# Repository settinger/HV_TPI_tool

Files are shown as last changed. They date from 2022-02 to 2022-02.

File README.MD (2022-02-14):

# High-Voltage Tiny Programming Interface (HVTPI) Tool

For an upcoming project I needed a way to use the High-Voltage Tiny Programming Interface (HVTPI) protocol. If you're at all familiar with the High-Voltage Serial Programming (HVSP) that can be used on most ATmegas and ATtinys that use the SPI protocol, then you would be justified to assume HVTPI is a convoluted process dissimilar from standard TPI. But, mercifully, that is not the case! HVTPI is just TPI, but instead of pulling the <span style="text-decoration:overline">RESET</span> pin LOW, you pull it up to 12V.

Two low-cost options for TPI programming are the [USBasp](https://www.fischl.de/usbasp/) (with the [latest firmware](https://blog.podkalicki.com/how-to-update-avr-usbasp-firmware-to-latest-version/)) or the [TPI Programming Arduino Sketch](http://junkplusarduino.blogspot.com/p/attiny10-resources.html) by Junk+Arduino and others. Neither the USBasp nor the Arduino has a pin available to output 12V, of course. That requires some extra hardware.

The task is easy to summarize. Create a new signal that produces 5V when <span style="text-decoration:overline">RESET</span> produces 5V, and goes to 12V when <span style="text-decoration:overline">RESET</span> goes to 0V. On YouTube, [fVripple made a very good one with an optoisolator and a benchtop power supply](https://www.youtube.com/watch?v=7YJOtHbnNDQ), but I wanted to stick to parts I had on-hand and make it more portable. This is what I came up with:

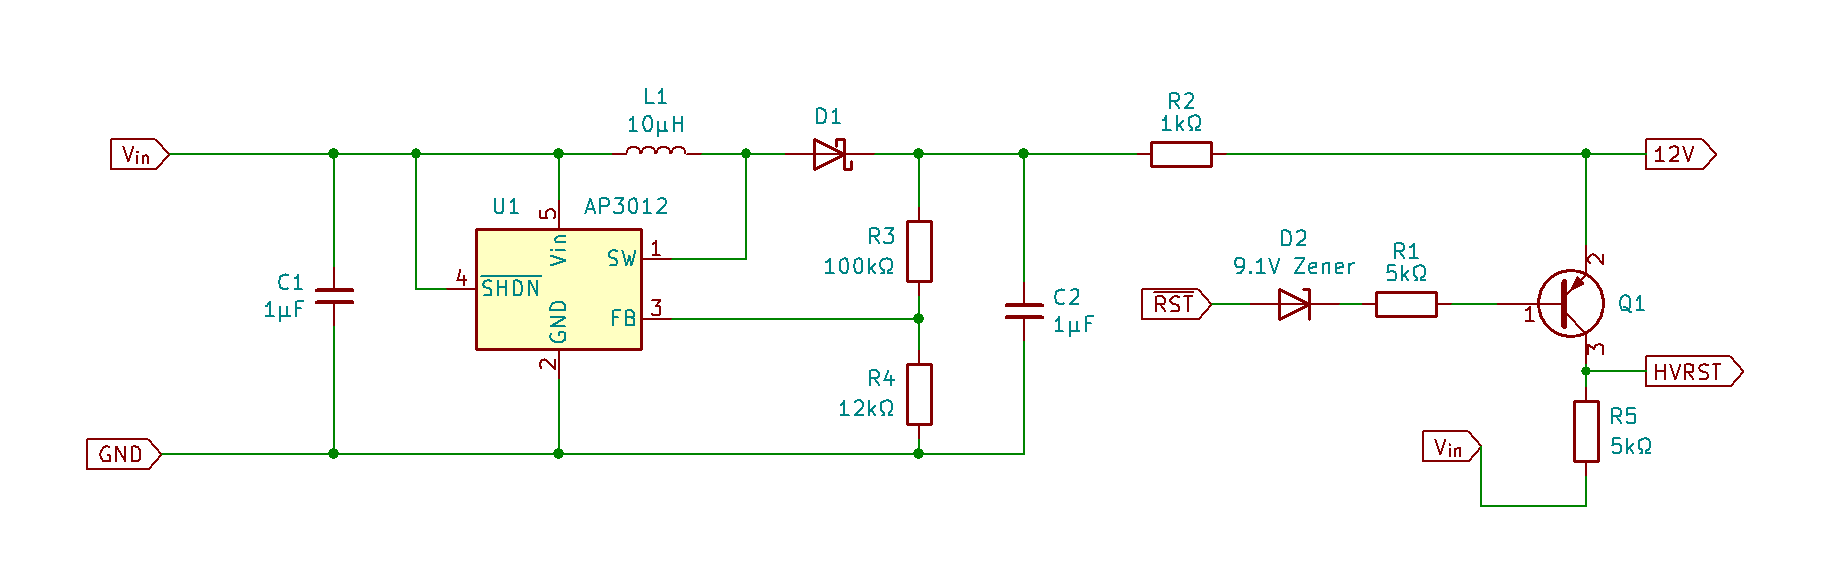
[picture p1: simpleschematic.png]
A schematic showing a 12V boost converter and an output that switches between 12V and 5V


An AP3012 boost converter gives us 12V all the time. While <span style="text-decoration:overline">RESET</span> is HIGH, the forward voltage of the Zener diode is high enough that no current flows through the PNP BJT and the output is equal to <span style="text-decoration:overline">RESET</span>. When <span style="text-decoration:overline">RESET</span> goes LOW, current flows through the 9.1V Zener diode, driving the output to 12V. The 5kΩ resistor value is not a precise one; I think I used 3.3kΩ in practice. And I broke out the 12V signal in case I ever wanted to use it for something else, I dunno what though.

To actually use this schematic, I made two designs: one to go with the USBasp and one to go with the Arduino TPI programmer. I was very sleep-deprived and made some silly design choices.

## The USBasp HVTPI tool

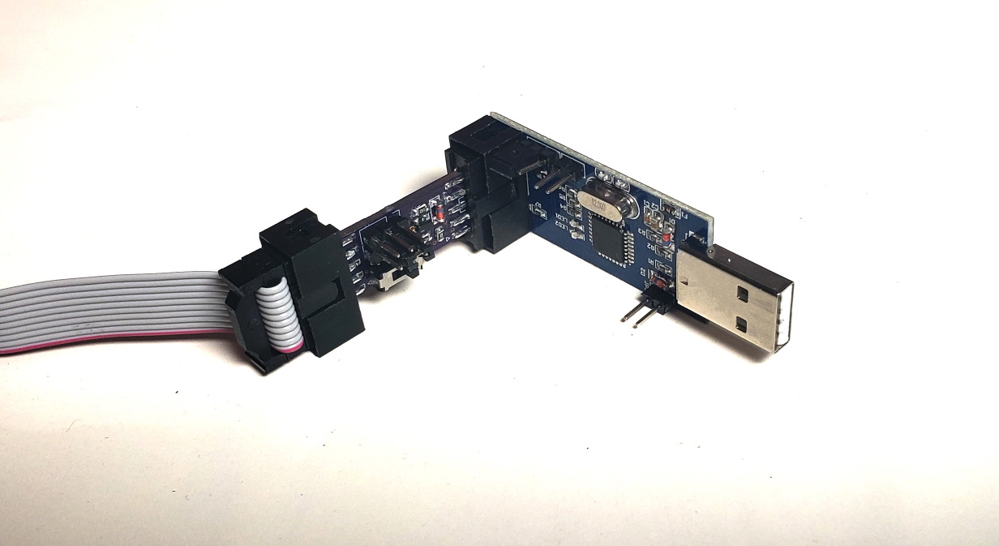
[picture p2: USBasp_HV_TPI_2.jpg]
A photo of the HVTPI PCB inserted into the end of a USBasp programmer


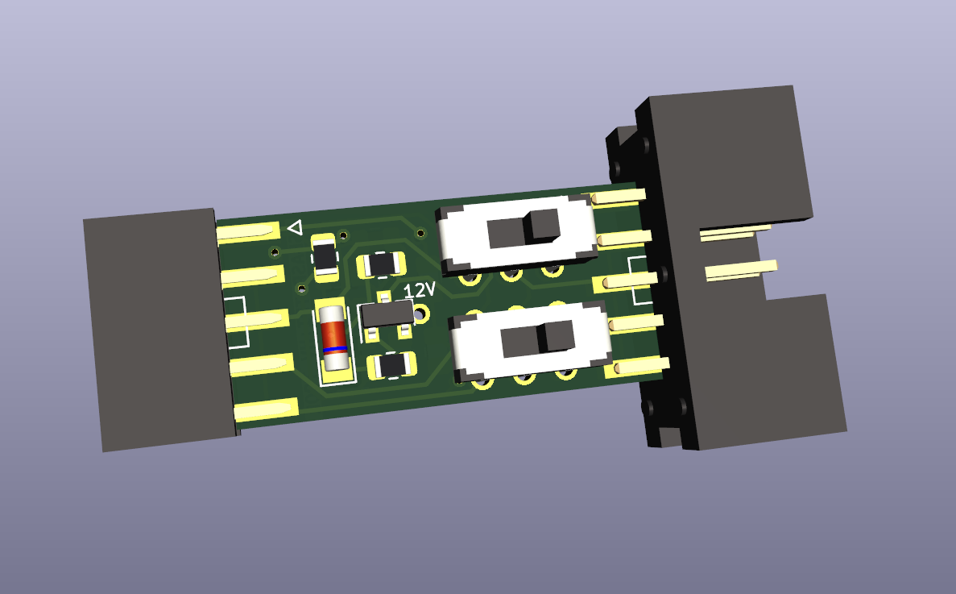
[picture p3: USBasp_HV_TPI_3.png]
A KiCad render of the HVTPI PCB


The USBasp HVTPI tool mates nicely with its 2×5 IDC headers. There are two SPDT switches, one to switch between normal TPI and HVTPI modes, and another to combine the two data lines as described in [this application note](http://ww1.microchip.com/downloads/en/AppNotes/doc8373.pdf):

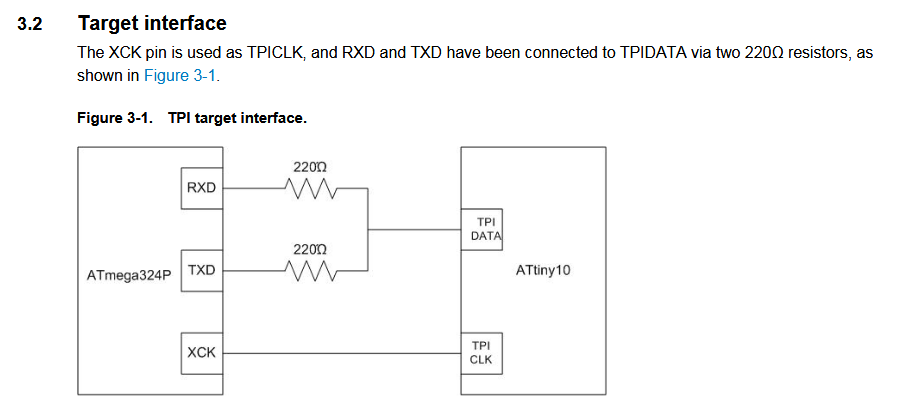
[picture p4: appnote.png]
A diagram from a Microchip application note showing how it recommends connecting an ATtiny10 to a programmer with a 220Ω resistor on each data line


These resistors are not always necessary, which is why they can be disconnected with the switch. The USBasp expects a circuit with a programming pinout like this:

A 2-by-3 pinout diagram showing (from top-left counterclockwise) (NC), TPICLK, ~RESET, GND, TPIDATA, VCC

Consequently, the line that is normally labelled "MOSI" acts as the bidirectional line when the USBasp does TPI stuff. This becomes a problem if you are using a circuit that was designed for the [Atmel-ICE](https://ww1.microchip.com/downloads/en/DeviceDoc/Atmel-ICE_UserGuide.pdf), which expects a programming pinout like this:

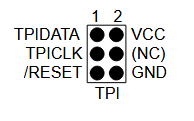
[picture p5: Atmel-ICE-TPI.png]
A 2-by-3 pinout diagram showing (from top-left counterclockwise) TPIDATA, TPICLK, ~RESET, GND, (NC), VCC


Both configurations are handled equally well by the 220Ω-resistor switch.

Using the HVTPI tool is as easy as normal TPI. As far as your computer is concerned, there is no difference between this and a normal TPI setup, so no instructions or makefiles have to change.

## The Arduino HVTPI tool

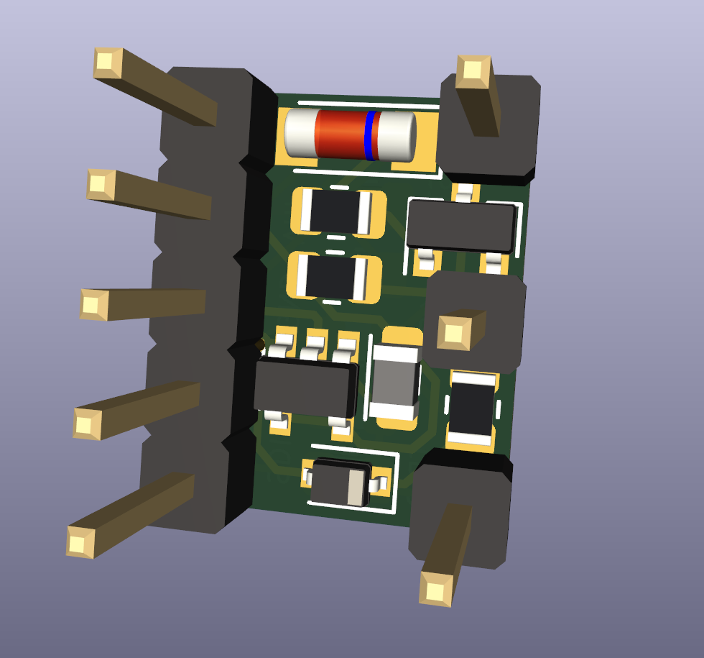
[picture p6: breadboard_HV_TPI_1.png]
A KiCad render of a surface-mount PCB the size of a 10-DIP chip


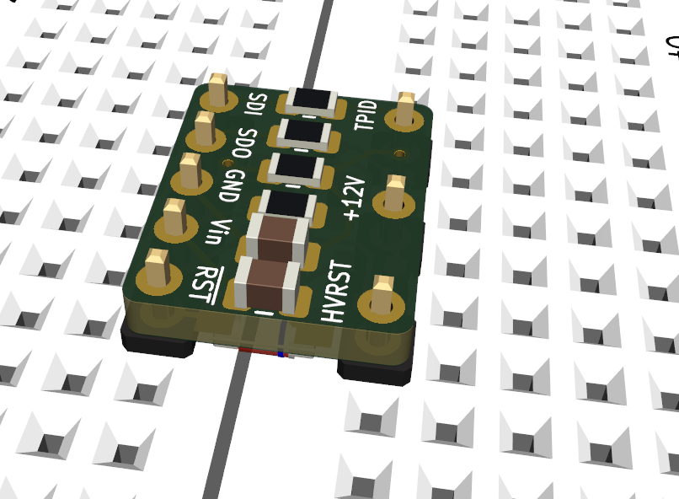
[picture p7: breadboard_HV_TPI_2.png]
A KiCad render of the same PCB placed on a breadboard


The Arduino-compatible programmer is designed to sit in a breadboard. I originally designed it very skinny, with the HVRST line sticking up like so:

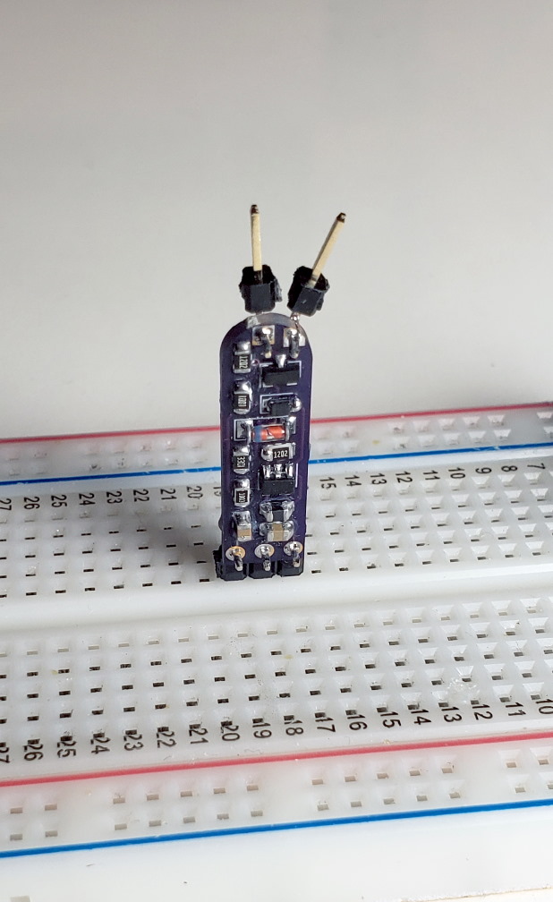
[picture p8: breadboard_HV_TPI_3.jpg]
A photo of the earlier design, which is skinny and tall and has two pins at weird angles sticking out of the top


This is not very helpful, so later I went back and put it in a more reasonable 10-DIP layout. Because the Arduino program expects both MISO and MOSI lines to connect to the TPI DATA line via 220Ω resistors, I built that into this board as well. Again, there is no need to make any changes to the normal TPI programming workflow. I know the Arduino sketch has some "HVP" options available, but with this board they are wholly unnecessary.

I'm happily using these with both the USBasp and the Arduino for HVTPI programming. I had a hard time finding good resources for HVTPI and had to do a lot of learning-by-doing, but hopefully I can pass that knowledge along and save someone some trouble.

# Note to self

After setting the ATtiny4/5/9/10/20/40 fuse bits to `0xFE` (or whatever) to enable 12V reset, avrdude can't just overwrite the fuses with `0xFF`. Using the flags `-x section_config -e` will clear the bits.

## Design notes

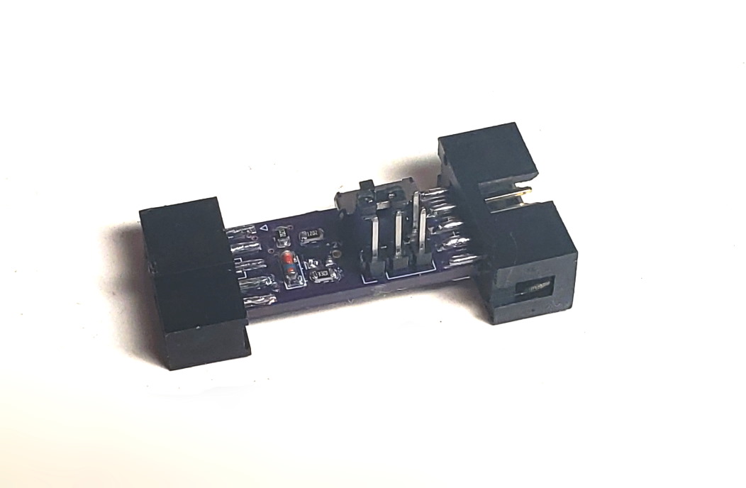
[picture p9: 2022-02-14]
USBasp_HV_TPI_1.jpg

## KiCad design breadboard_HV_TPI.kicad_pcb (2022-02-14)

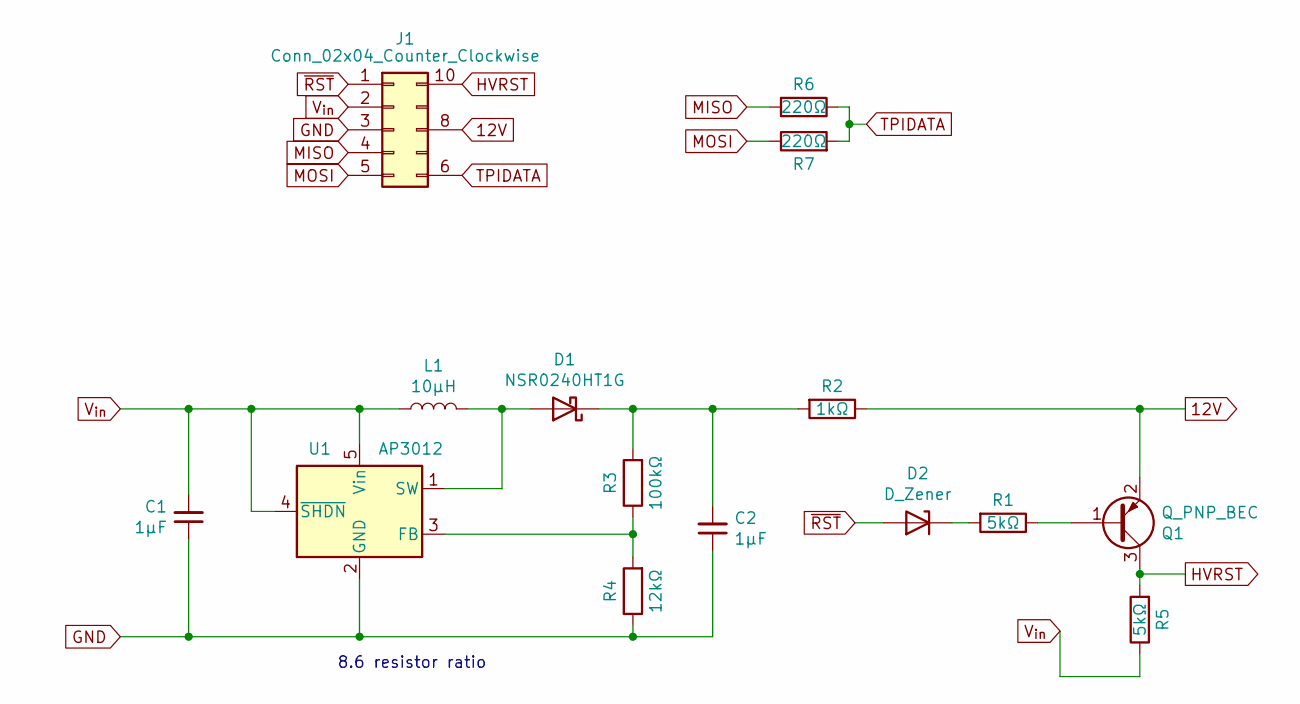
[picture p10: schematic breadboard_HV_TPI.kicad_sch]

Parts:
C1, C2: 1μF; C_0805_2012Metric
D1: NSR0240HT1G; D_SOD-323
D2: D_Zener; D_MiniMELF
J1: Conn_02x04_Counter_Clockwise; DIP-10_W7.62mm
L1: 10μH; L_0805_2012Metric
Q1: Q_PNP_BEC; SOT-23
R1, R5: 5kΩ; R_0805_2012Metric
R2: 1kΩ; R_0805_2012Metric
R3: 100kΩ; R_0805_2012Metric
R4: 12kΩ; R_0805_2012Metric
R6, R7: 220Ω; R_0805_2012Metric
U1: AP3012; SOT-23-5

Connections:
12V: J1.8, Q1.2 (E), R2.1
GND: C1.1, C2.1, J1.3, R4.1, U1.2 (GND)
HVRST: J1.10, Q1.3 (C), R5.2
MISO: J1.4, R6.2
MOSI: J1.5, R7.1
unnamed: C2.2, D1.1 (K), R2.2, R3.2
unnamed: D1.2 (A), L1.2, U1.1 (SW)
unnamed: D2.1 (K), R1.2
unnamed: Q1.1 (B), R1.1
unnamed: R3.1, R4.2, U1.3 (FB)
TPIDATA: J1.6, R6.1, R7.2
V_{in}: C1.2, J1.2, L1.1, R5.1, U1.4 (~SHDN), U1.5 (Vin)
~RST: D2.2 (A), J1.1

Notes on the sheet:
8.6 resistor ratio

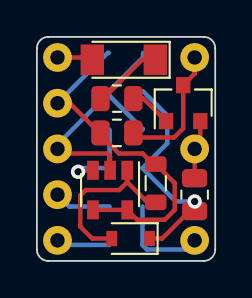
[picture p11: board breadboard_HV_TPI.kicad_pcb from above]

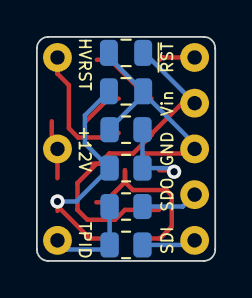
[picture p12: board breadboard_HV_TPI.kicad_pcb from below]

Board: 2 copper layers, 9.9 x 12.4 mm, 15 parts (6 on the bottom side), 13 nets.

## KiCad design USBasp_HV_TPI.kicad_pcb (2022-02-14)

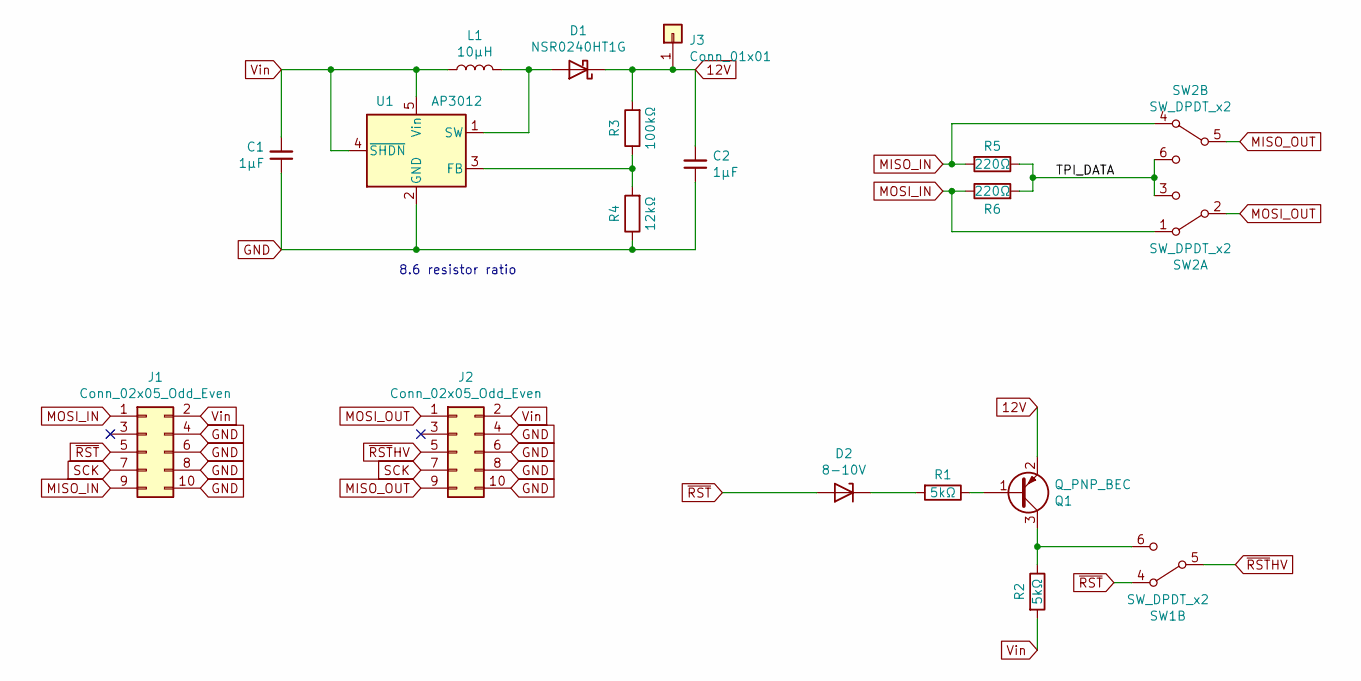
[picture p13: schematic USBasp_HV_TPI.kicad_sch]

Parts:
C1, C2: 1μF; C_0805_2012Metric
D1: NSR0240HT1G; D_SOD-323
D2: 8-10V; D_MiniMELF
J1: Conn_02x05_Odd_Even; IDC_Socket_2x05_P2.54mm_edge-mount
J2: Conn_02x05_Odd_Even; IDC_Header_2x05_P2.54mm_edge-mount
J3: Conn_01x01; PinHeader_1x01_P2.54mm_Vertical
L1: 10μH; L_0805_2012Metric
Q1: Q_PNP_BEC; SOT-23
R1, R2: 5kΩ; R_0805_2012Metric
R3: 100kΩ; R_0805_2012Metric
R4: 12kΩ; R_0805_2012Metric
R5, R6: 220Ω; R_0805_2012Metric
SW1, SW2: SW_DPDT_x2; SW_CuK_JS202011CQN_DPDT_Straight
U1: AP3012; SOT-23-5

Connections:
12V: C2.2, D1.1 (K), J3.1, Q1.2 (E), R3.2
/TPI_DATA: R5.1, R6.2, SW2.3 (C), SW2.6 (C)
GND: C1.1, C2.1, J1.4, J1.6, J1.8, J1.10, J2.4, J2.6, J2.8, J2.10, R4.1, U1.2 (GND)
MISO_IN: J1.9, R5.2, SW2.4 (A)
MISO_OUT: J2.9, SW2.5 (B)
MOSI_IN: J1.1, R6.1, SW2.1 (A)
MOSI_OUT: J2.1, SW2.2 (B)
unnamed: D1.2 (A), L1.2, U1.1 (SW)
unnamed: D2.1 (K), R1.2
unnamed: Q1.1 (B), R1.1
unnamed: Q1.3 (C), R2.1, SW1.6 (C)
unnamed: R3.1, R4.2, U1.3 (FB)
SCK: J1.7, J2.7
Vin: C1.2, J1.2, J2.2, L1.1, R2.2, U1.4 (~SHDN), U1.5 (Vin)
~RST: D2.2 (A), J1.5, SW1.4 (A)
~RSTHV: J2.5, SW1.5 (B)

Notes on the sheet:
8.6 resistor ratio

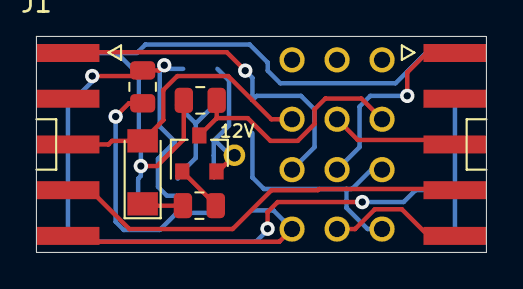
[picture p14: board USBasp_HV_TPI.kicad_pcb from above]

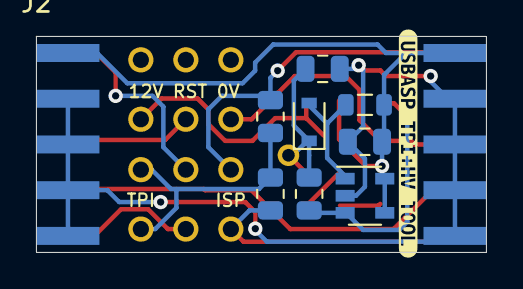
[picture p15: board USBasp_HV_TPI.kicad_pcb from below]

Board: 2 copper layers, 25.0 x 12.0 mm, 19 parts (11 on the bottom side), 16 nets.

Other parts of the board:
svg2mod: G***; label
